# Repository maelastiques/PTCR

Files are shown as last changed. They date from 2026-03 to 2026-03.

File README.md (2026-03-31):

# PTCR -- Portable Text Communication Radio

PTCR (**Portable Text Communication Radio**) is an open hardware
LoRa-based handheld communication device designed for off‑grid
messaging.

The goal of this project is to build a **fully self‑contained radio
communicator** that can operate without cellular infrastructure,
allowing users to exchange text messages over long distances using LoRa
technology.

This project was created by **Maël**, a developer and hardware tinkerer
who enjoys:

-   hiking
-   autonomy and off‑grid systems
-   nomadic lifestyles
-   building and experimenting with electronics
-   creating whatever ideas come to mind

The idea behind PTCR came from the desire to have a **nomadic
communication tool** that works during hikes, expeditions, or remote
travel --- without relying on mobile networks.

Instead of buying a commercial device, the obvious solution was to
**build one**.

------------------------------------------------------------------------

# Device Preview

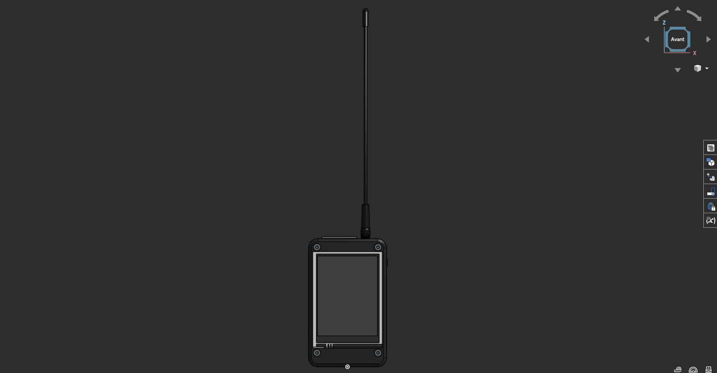
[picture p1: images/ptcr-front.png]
Device photo 1
 *Front view of the device*

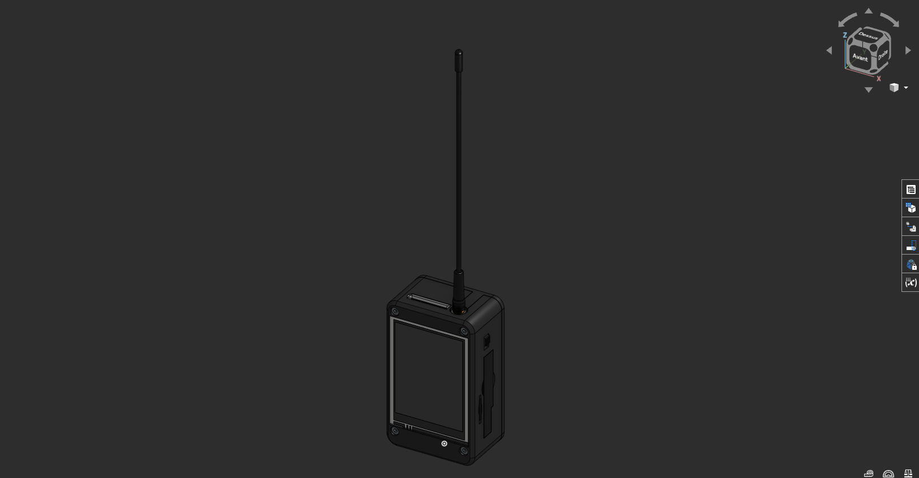
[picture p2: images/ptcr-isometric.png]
Device photo 2
 *Isometric view*

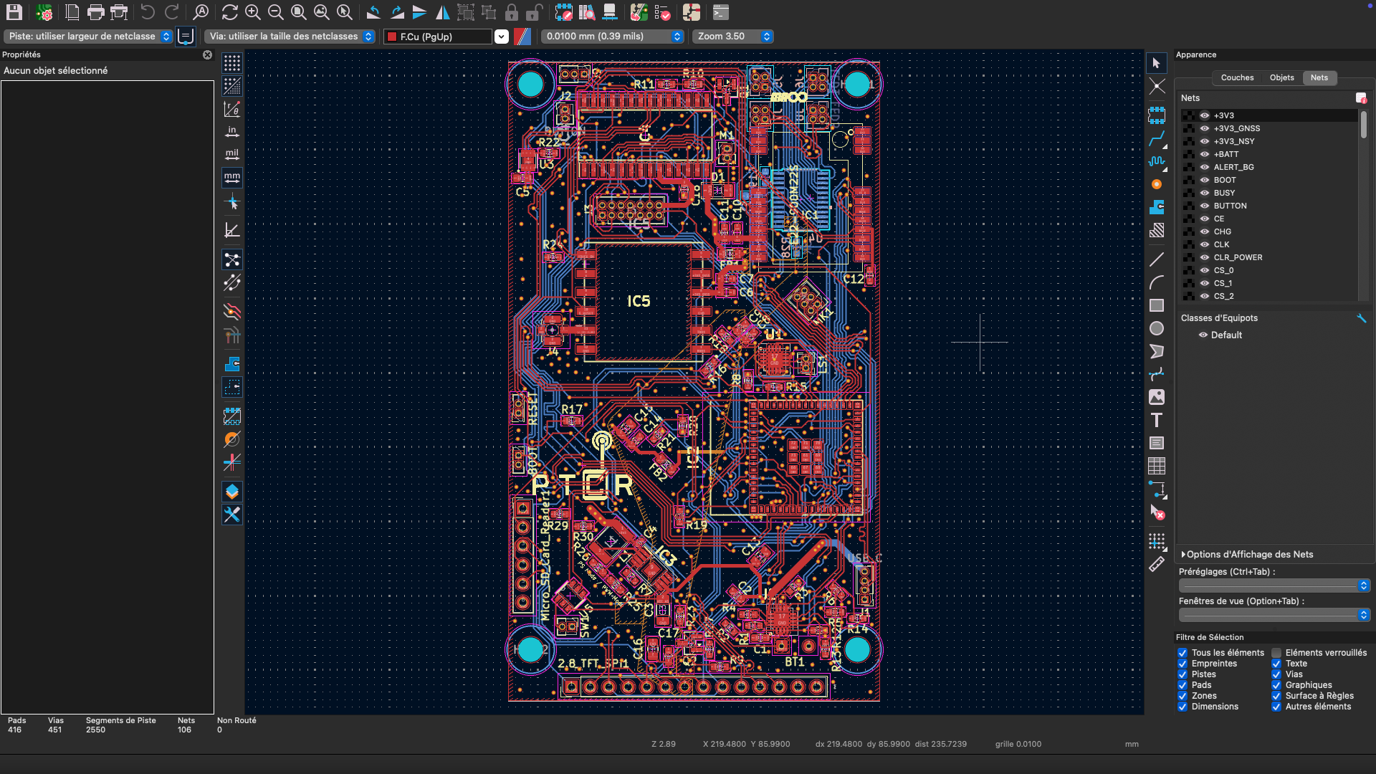
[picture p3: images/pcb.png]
Device photo 3
 *Internal electronics*

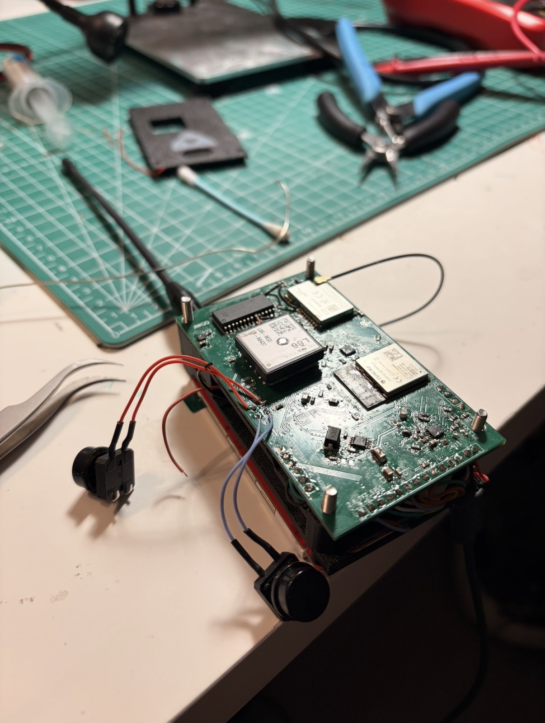
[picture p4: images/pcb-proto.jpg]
Device photo 4
 *Prototype board*

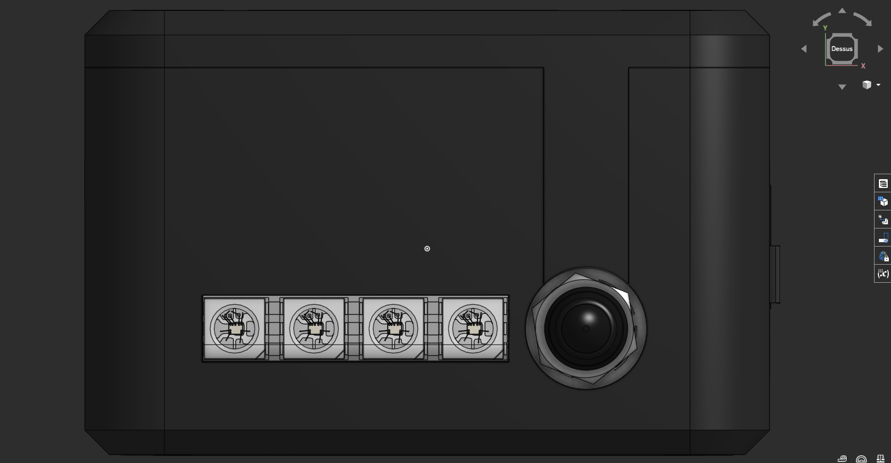
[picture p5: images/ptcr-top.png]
 *Top of the device*

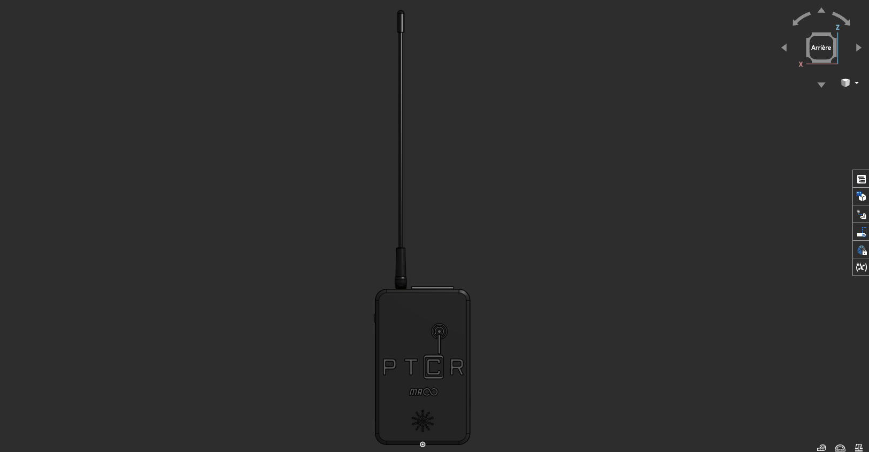
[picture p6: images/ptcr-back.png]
 *Back of the device*

------------------------------------------------------------------------

# Features

-   **LoRa long‑range communication**
-   **GNSS positioning (GPS / GLONASS)**
-   **SPI TFT display**
-   **microSD storage**
-   **LiPo battery powered**
-   **High‑efficiency 3.3V buck regulator**
-   **Open hardware**
-   Designed for **off‑grid and nomadic use**

------------------------------------------------------------------------

# Hardware Overview

The system is built around several main components:

  Component      Role
  -------------- --------------------------
  ESP32‑S3       Main MCU
  E22‑900M22S    LoRa radio module
  Quectel L86    GNSS receiver
  MCP23017       I²C GPIO expander
  TFT display    User interface
  microSD        Data storage
  TPS62842       3.3V switching regulator
  LiPo battery   Power source
  LP5012         12 PWM canals led module
  MAX16150       switch ON/OFF with push button

The PCB uses a **4‑layer stackup**:

-   Top layer: signals
-   Internal layer: **solid ground plane**
-   Internal layer: **3.3V power plane**
-   Bottom layer: signals + ground pour

This architecture improves signal integrity and RF performance.

------------------------------------------------------------------------

# Schematic

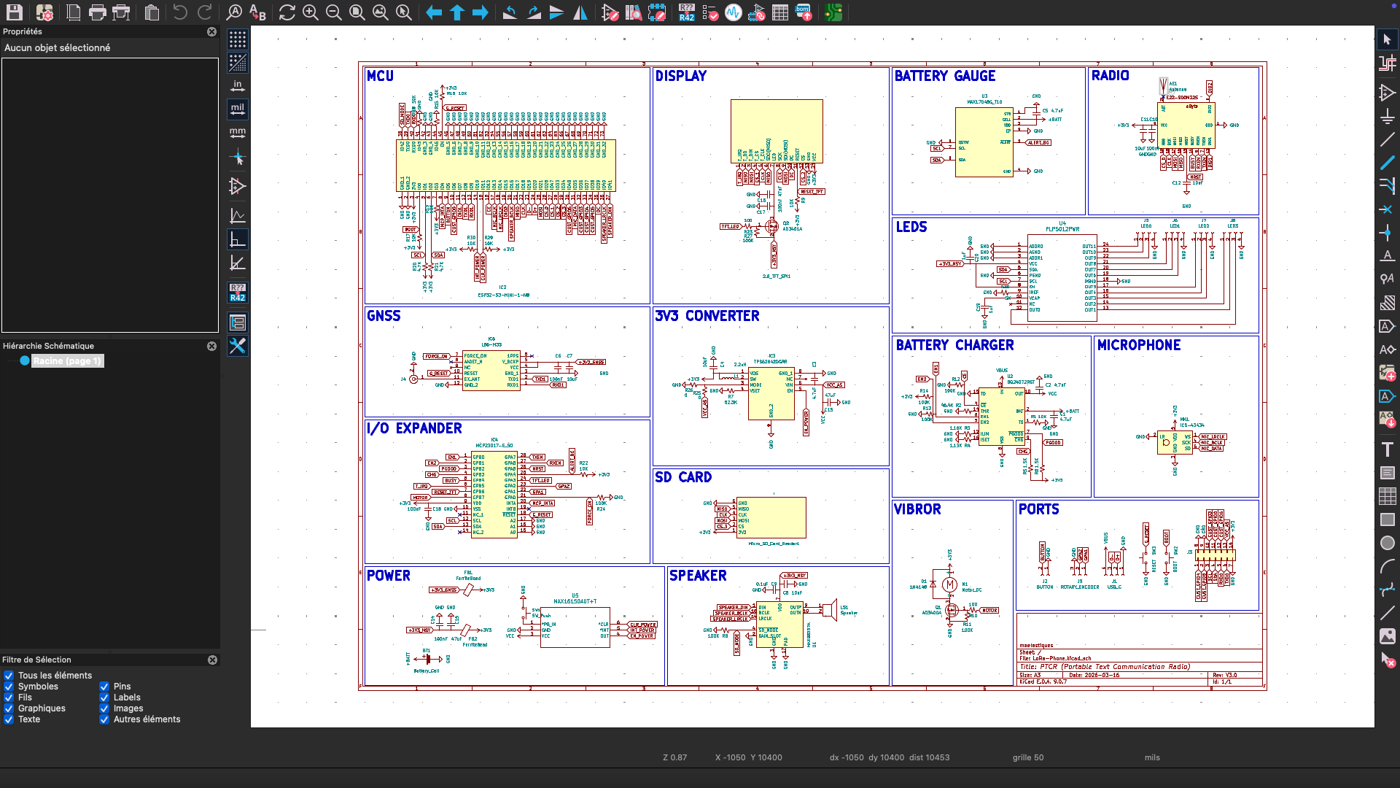
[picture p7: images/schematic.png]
PTCR schematic


------------------------------------------------------------------------

# Pin Mapping

## LoRa Module -- E22‑900M22S

  Signal   Direction    Description
  -------- ------------ ----------------------
  MISO     LoRa → MCU   SPI data from radio
  MOSI     MCU → LoRa   SPI data to radio
  SCK      MCU → LoRa   SPI clock
  NSS      MCU → LoRa   Chip select
  BUSY     LoRa → MCU   Radio busy indicator
  DIO1     LoRa → MCU   Interrupt
  RXEN     MCU → LoRa   Enable RX
  TXEN     MCU → LoRa   Enable TX
  NRST     MCU → LoRa   Reset

RXEN and TXEN are pulled down by default to guarantee a safe startup
state.

------------------------------------------------------------------------

## GNSS -- Quectel L86

  Signal   Direction       Description
  -------- --------------- ---------------
  TX       GNSS → MCU      NMEA output
  RX       MCU → GNSS      configuration
  V_BCKP   backup supply   RTC retention

------------------------------------------------------------------------

## MCP23017 -- GPIO Expander

Connected through **I²C**.

  Signal       Description
  ------------ ---------------
  SDA          I²C data
  SCL          I²C clock
  GPA0--GPA7   extended GPIO
  GPB0--GPB7   extended GPIO

Used for additional control signals and hardware expansion.

------------------------------------------------------------------------

## TFT Display (SPI)

  Signal   Description
  -------- ----------------
  MOSI     SPI data
  SCK      SPI clock
  CS       Chip select
  DC       Data / command
  RST      Reset
  BL       Backlight

------------------------------------------------------------------------

## microSD

  Signal   Description
  -------- -------------
  MOSI     SPI data
  MISO     SPI data
  SCK      SPI clock
  CS       Chip select

Shared SPI bus with other peripherals.

------------------------------------------------------------------------

## Leds module

  Connected through **I²C**.

  Signal       Description
  ------------ ---------------
  SDA          I²C data
  SCL          I²C clock
  OUT0-OUT11   12 PWM canals

Used for 4 RGB leds

------------------------------------------------------------------------

## ON/OFF module

  Signal       Description
  ------------ ---------------
  PB_IN        Button
  CLR          Input signal
  INT          Output signal

Used for turning ON and OFF the regulator

------------------------------------------------------------------------

# Power System

Power is supplied by a **single‑cell LiPo battery**.

A **TPS62842 buck converter** generates the **3.3V system rail**.

The design includes:

-   local decoupling capacitors
-   ferrite filtering
-   ground stitching vias
-   separated noisy power domains

This ensures stable operation for RF, GNSS, and digital circuits.

------------------------------------------------------------------------

# Firmware (planned)

The ESP32 firmware will provide:

-   LoRa messaging
-   device‑to‑device communication
-   contact management
-   message history on SD card
-   GNSS position logging
-   graphical interface on TFT

Future ideas:

-   mesh networking
-   encrypted messaging
-   APRS beacon support
-   offline mapping

------------------------------------------------------------------------

# Motivation

This project combines several things I enjoy:

-   hiking
-   autonomy and self‑reliance
-   radio communication
-   embedded electronics
-   building experimental devices

PTCR is meant to be a **portable communication device for nomadic use**,
especially when exploring places without network coverage.

And most importantly --- it was simply fun to build.

------------------------------------------------------------------------

# Project Status

Prototype stage !

Current revision: **PTCR V3**

Hardware and firmware are actively being developed.

------------------------------------------------------------------------

# Author

**Maël CUNY**

Software developer, robotics enthusiast, and hardware builder.

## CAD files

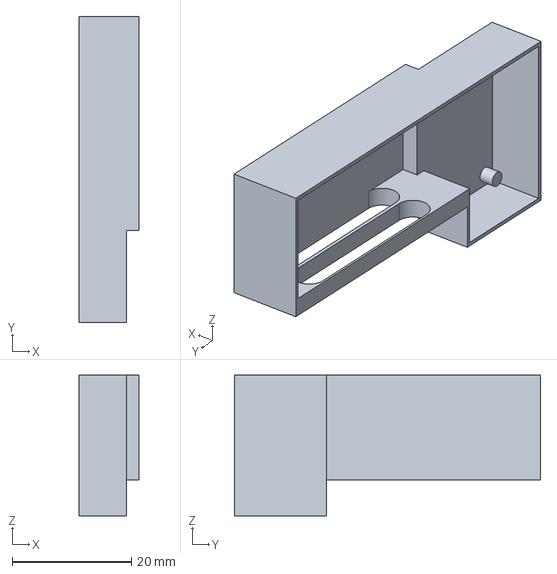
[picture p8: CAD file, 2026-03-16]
CAD/PTCR-MODULE.step
10.1 x 51.3 x 23.6 mm

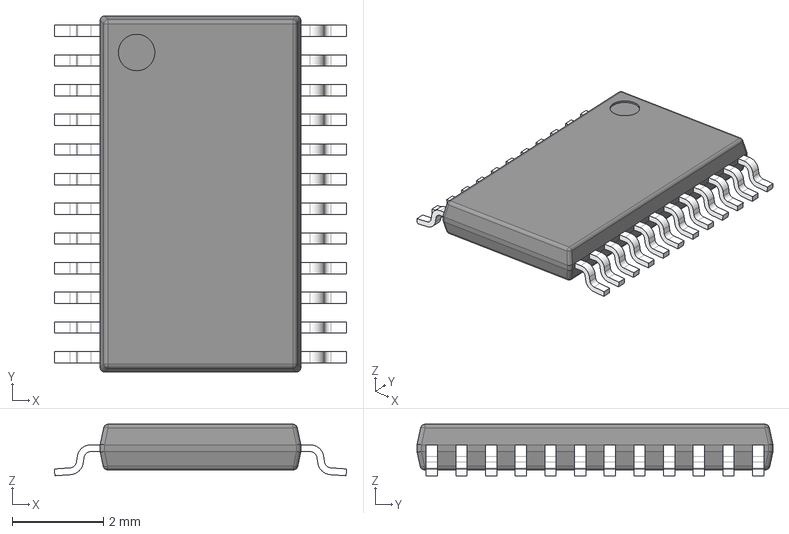
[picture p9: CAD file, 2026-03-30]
components-models/PW0024A.stp
6.40 x 7.80 x 1.13 mm
BODY-TSSOP
LEAD-TSSOP x 24
PIN1

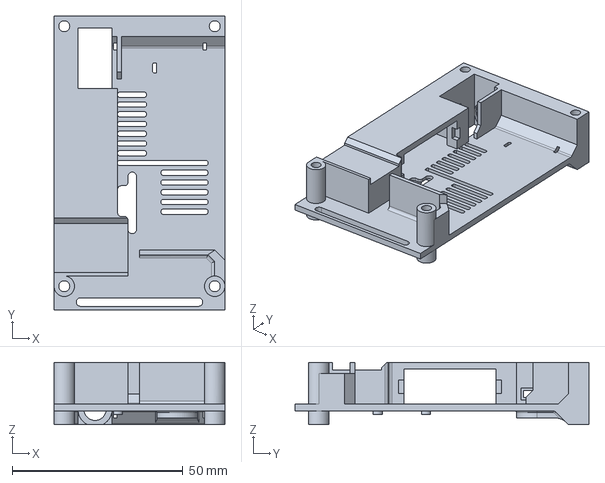
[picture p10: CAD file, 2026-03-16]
CAD/PTCR-BASE.step
50.0 x 86.0 x 18.2 mm

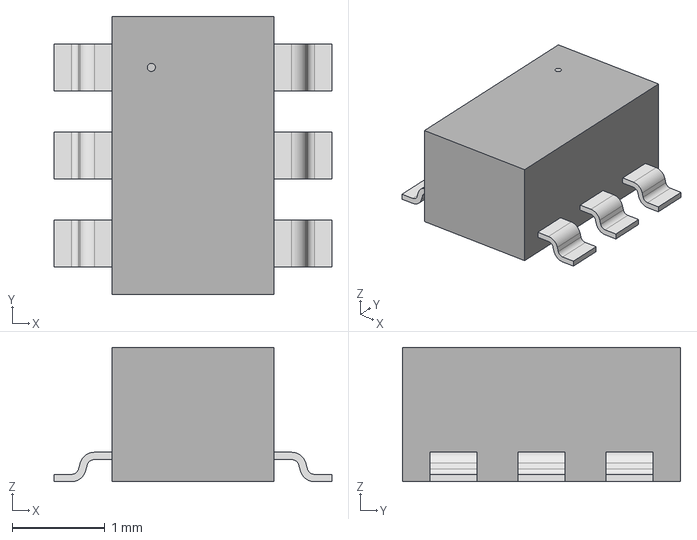
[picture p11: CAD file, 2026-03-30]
components-models/21-0058I_MXM.step
3.00 x 3.00 x 1.45 mm

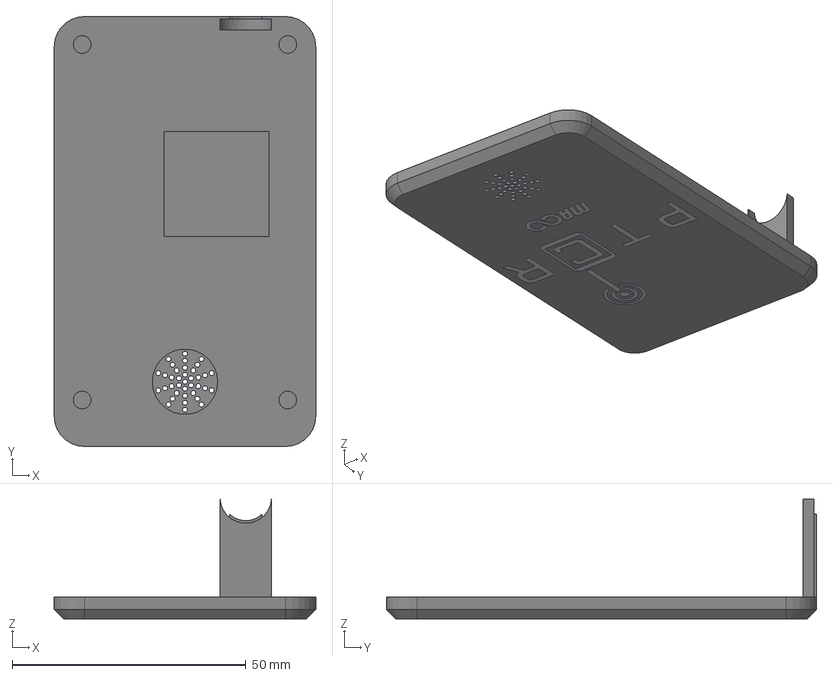
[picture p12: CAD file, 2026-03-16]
CAD/PTCR-CASING-BACK.step
56.0 x 92.0 x 25.6 mm

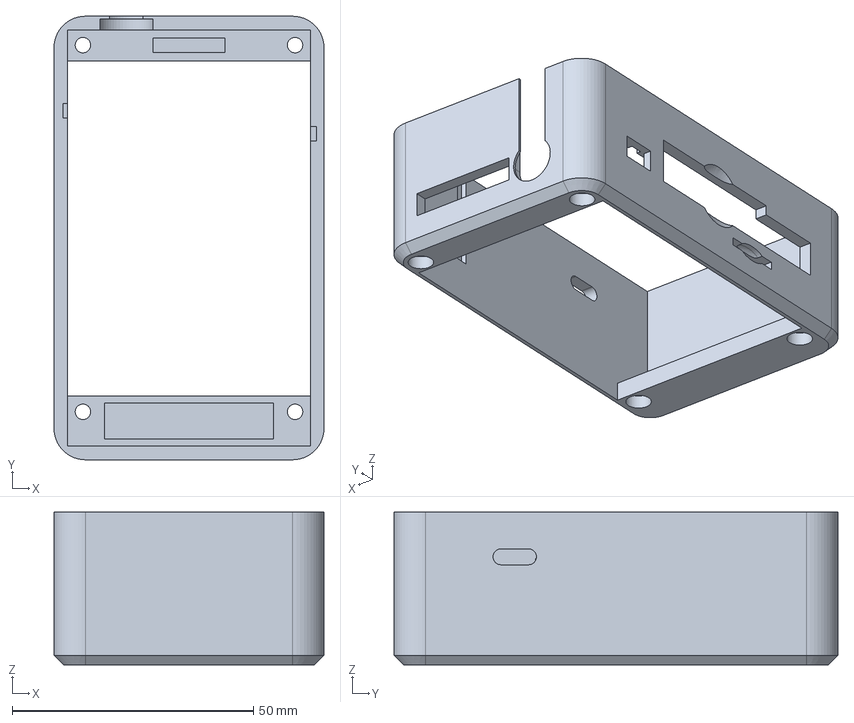
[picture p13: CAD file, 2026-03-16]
CAD/PTCR-CASING-FRONT.step
56.0 x 92.0 x 31.7 mm

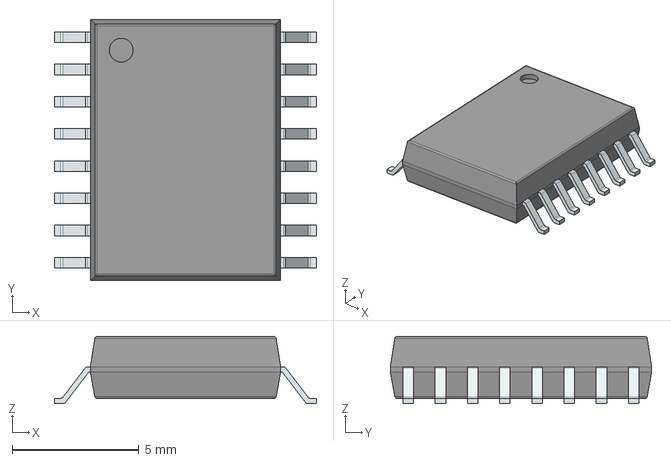
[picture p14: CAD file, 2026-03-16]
components-models/DS3231SNTR.stp
10.3 x 10.3 x 2.65 mm
PinsArrayLR

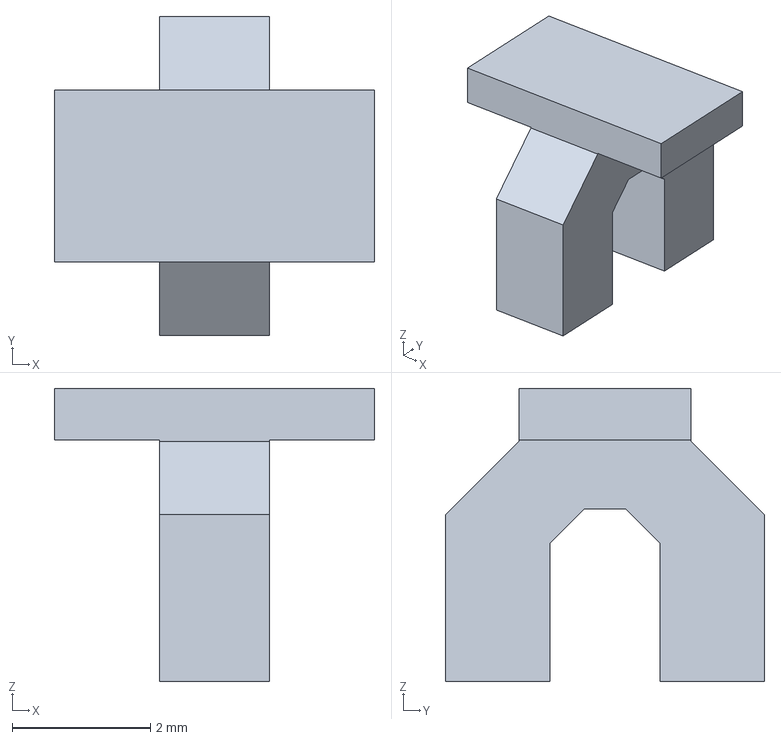
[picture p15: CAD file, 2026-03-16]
CAD/slide-switch-cover-2.step
4.64 x 4.62 x 4.25 mm

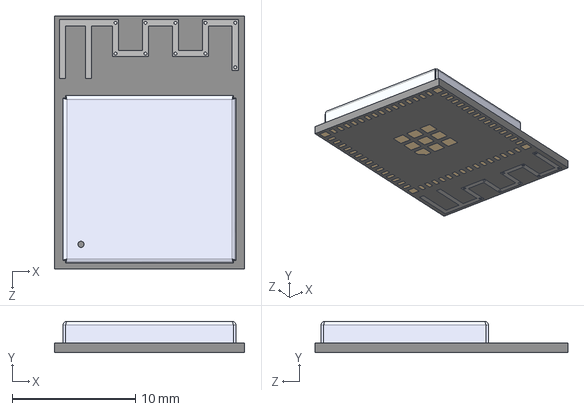
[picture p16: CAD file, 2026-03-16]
components-models/ESP32-S3-MINI-1-N8.stp
15.4 x 2.55 x 20.5 mm

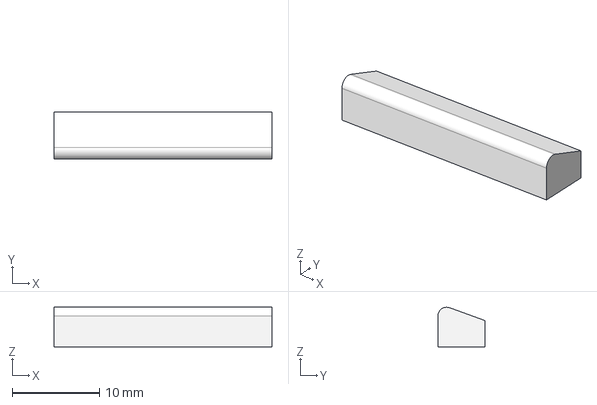
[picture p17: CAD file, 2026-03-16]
CAD/PTCR-LEDS-DIFFUSER.step
25.0 x 5.40 x 4.54 mm

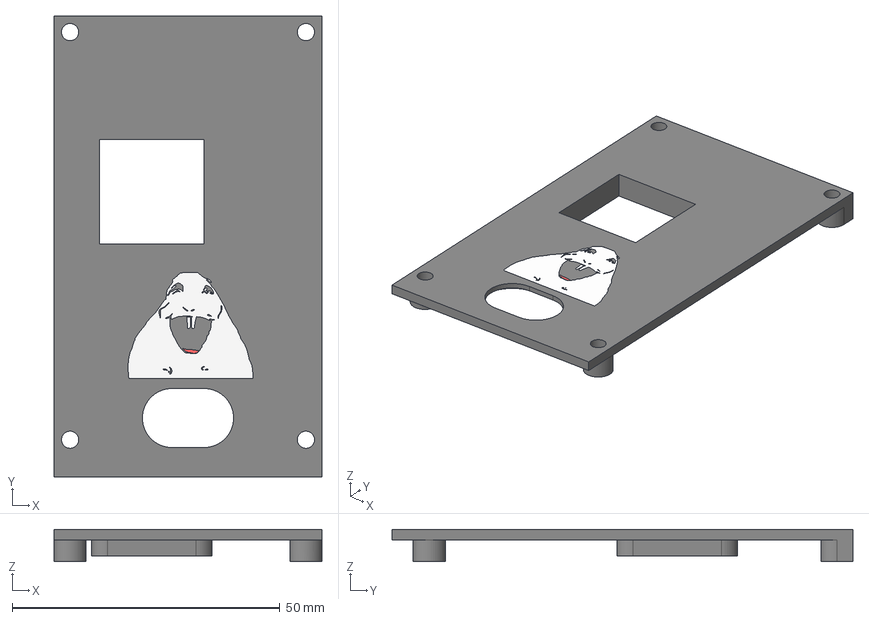
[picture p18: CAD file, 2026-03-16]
CAD/PTCR-BATTERY-HOLDER.step
50.0 x 86.0 x 6.00 mm

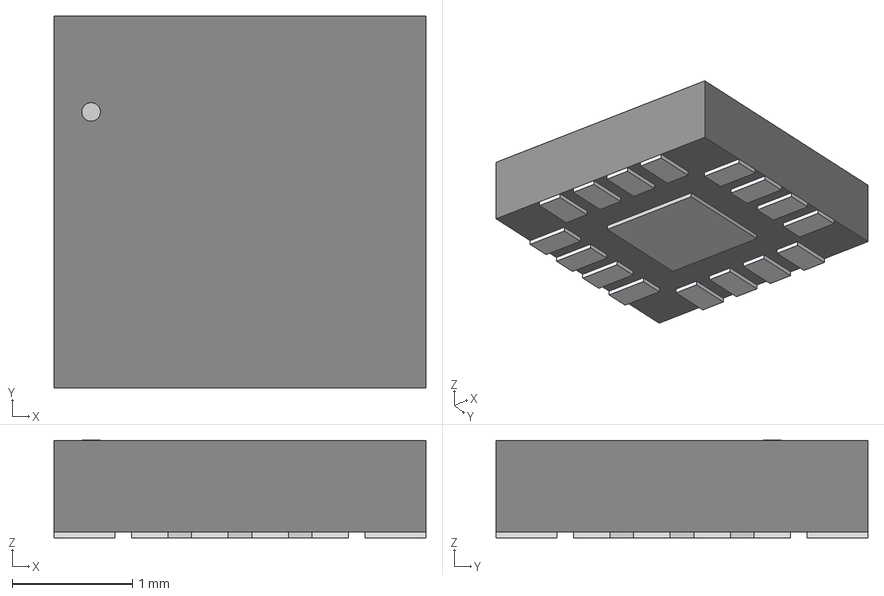
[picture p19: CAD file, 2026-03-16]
components-models/21-0136I_T1633-4_MXM.step
3.10 x 3.10 x 0.815 mm

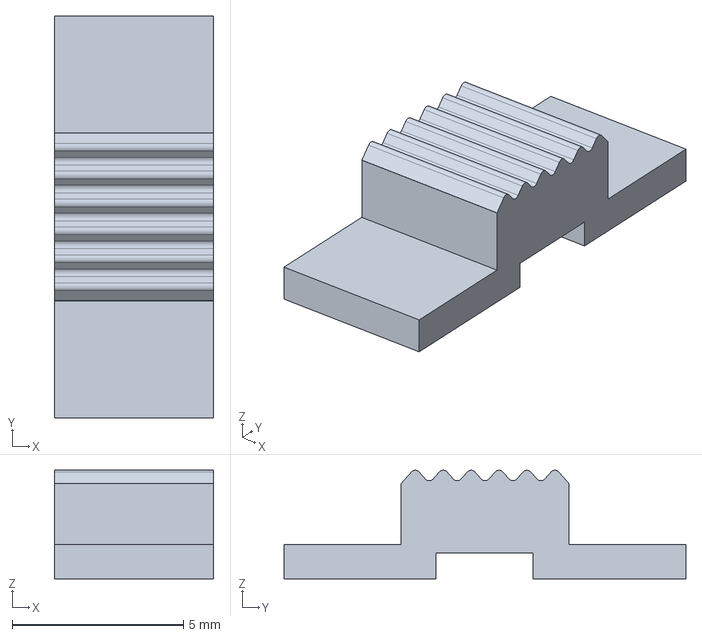
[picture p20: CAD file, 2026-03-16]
CAD/slide-switch-cover-1.step
4.65 x 11.8 x 3.17 mm

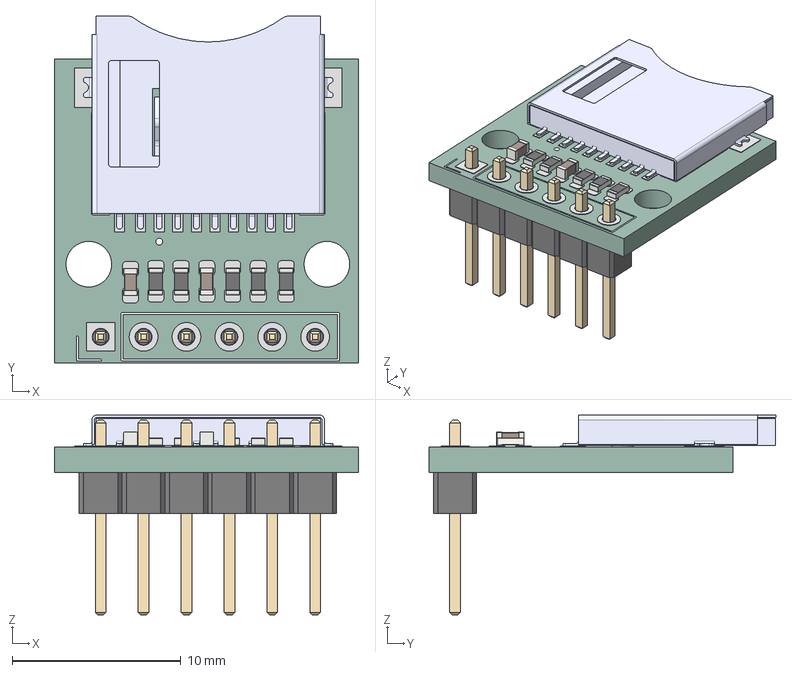
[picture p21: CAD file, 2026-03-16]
components-models/microSD_breakout_mini_pins.step
18.0 x 20.5 x 11.8 mm
R_0603_1608Metric x 5
C_0603_1608Metric x 2
MSD-11-A
PinHeader_1x06_P2.54mm_Vertical
microSD_breakout_mini_pad
microSD_breakout_mini_silkscreen x 2
microSD_breakout_mini_PCB

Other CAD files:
components-models/E22-900M22S.step
components-models/L86-M33.stp
components-models/TPS62842DGRR.stp
components-models/MCP23017-E_SO.stp
components-models/BQ24072RGTT.stp
components-models/MAX17048G_T10.step

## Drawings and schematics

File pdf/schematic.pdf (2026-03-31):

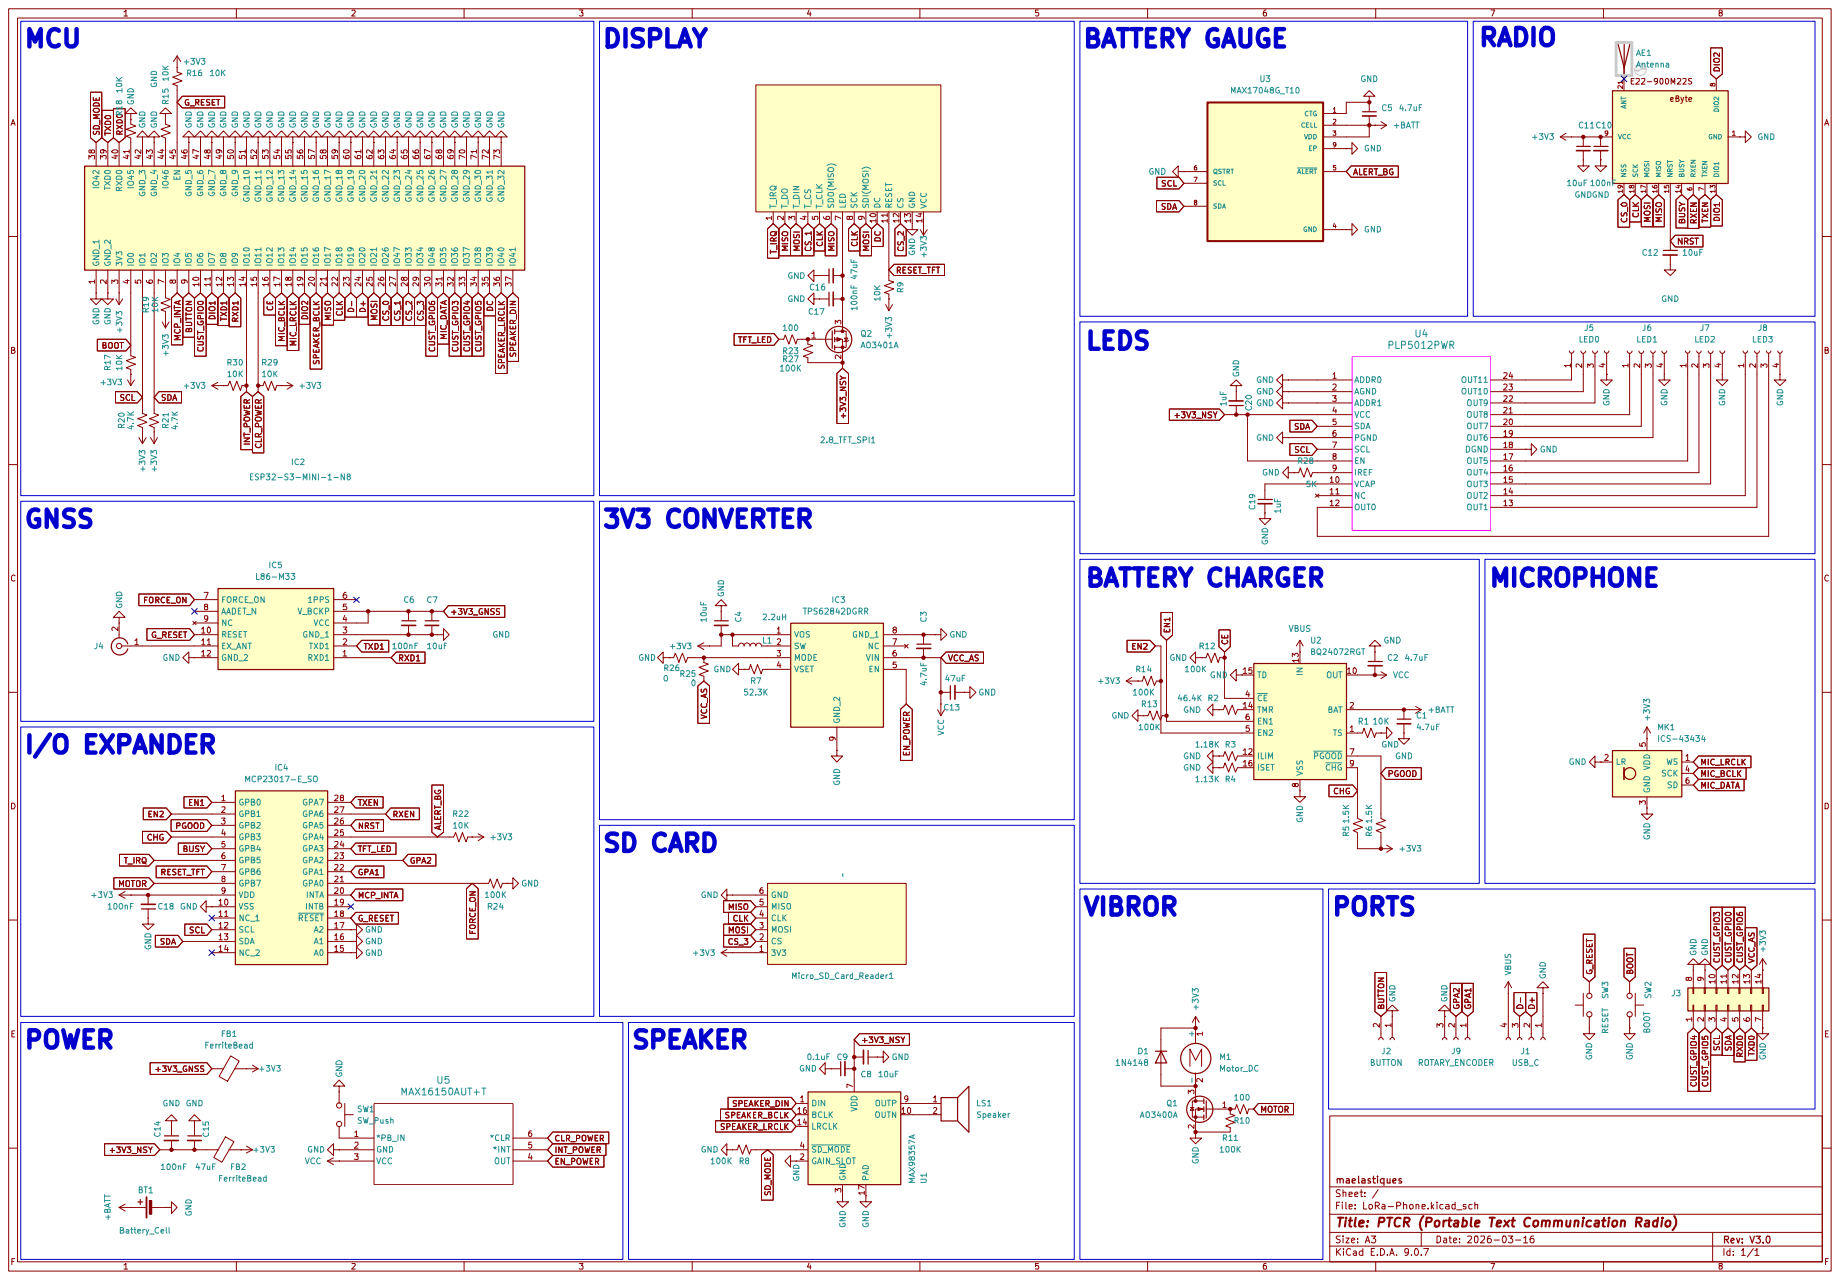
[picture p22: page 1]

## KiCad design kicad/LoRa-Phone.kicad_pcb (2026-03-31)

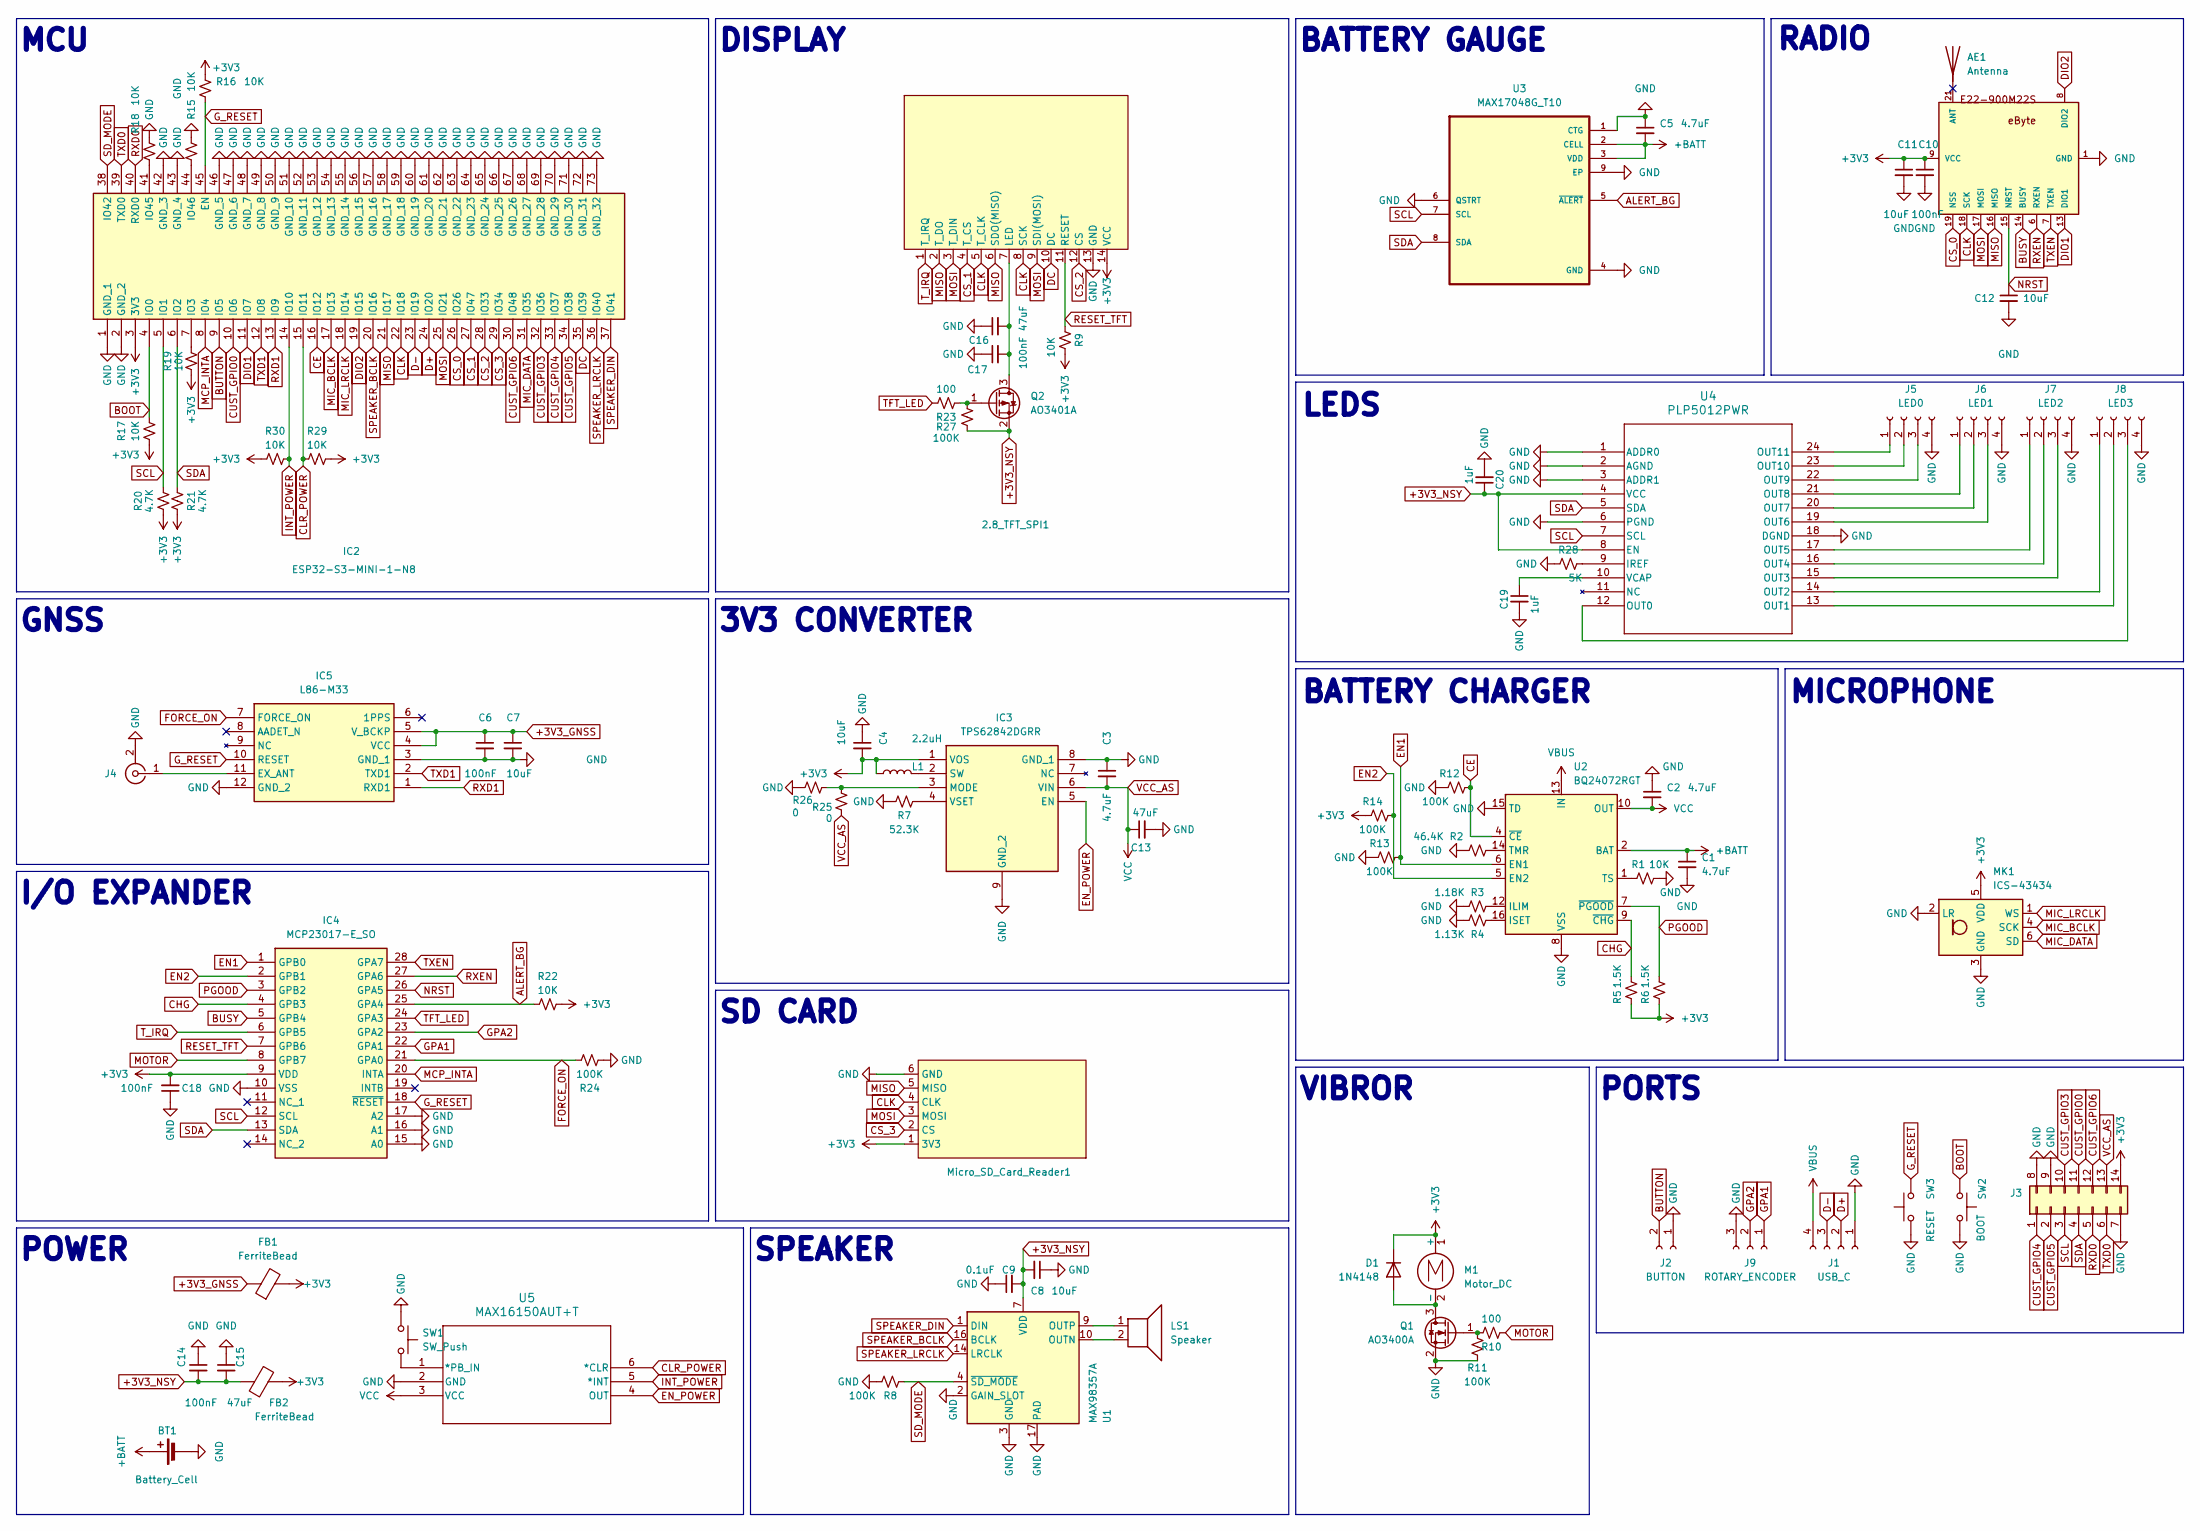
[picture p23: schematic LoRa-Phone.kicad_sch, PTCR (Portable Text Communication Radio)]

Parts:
2.8_TFT_SPI1: PinHeader_1x14_P2.54mm_Vertical
AE1: Antenna
BT1: Battery_Cell; SolderWire-0.1sqmm_1x02_P3.6mm_D0.4mm_OD1mm
C1, C2, C5: 4.7uF; C_0603_1608Metric
C3: 4.7uF; C_1206_3216Metric
C4: 10uF; C_0402_1005Metric
C6, C10, C14, C17, C18: 100nF; C_0603_1608Metric
C7, C8, C11, C12: 10uF; C_0603_1608Metric
C9: 0.1uF; C_0603_1608Metric
C13, C15, C16: 47uF; C_0805_2012Metric
C19, C20: 1uF; C_0603_1608Metric
D1: 1N4148; D_1206_3216Metric
FB1, FB2: FerriteBead; L_0805_2012Metric
IC1: E22-900M22S
IC2: ESP32-S3-MINI-1-N8; ESP32S3MINI1N8; Mouser Part Number 356-ESP32-S3-MINI1N8
IC3: TPS62842DGRR; SOP65P490X110-9N; Mouser Part Number 595-TPS62842DGRR
IC4: MCP23017-E_SO; SOIC127P1030X265-28N; Mouser Part Number 579-MCP23017-E/SO
IC5: L86-M33; L80-M39; Mouser Part Number 277-L86-M33
J1: USB_C; PinHeader_1x04_P1.27mm_Vertical
J2: BUTTON; PinHeader_1x02_P1.27mm_Vertical
J3: Conn_02x07_Top_Bottom; PinHeader_2x07_P1.27mm_Vertical
J4: Conn_Coaxial; U.FL_Molex_MCRF_73412-0110_Vertical
J5: LED0; PinHeader_2x02_P1.27mm_Vertical
J6: LED1; PinHeader_2x02_P1.27mm_Vertical
J7: LED2; PinHeader_2x02_P1.27mm_Vertical
J8: LED3; PinHeader_2x02_P1.27mm_Vertical
J9: ROTARY_ENCODER; PinHeader_1x03_P1.27mm_Vertical
L1: 2.2uH; L_1812_4532Metric
LS1: Speaker; PinHeader_1x02_P1.27mm_Vertical
M1: Motor_DC; PinHeader_1x02_P1.27mm_Vertical
MK1: ICS-43434; PinHeader_2x03_P1.27mm_Vertical
Micro_SD_Card_Reader1: PinHeader_1x06_P2.54mm_Vertical
Q1: AO3400A; SOT-23
Q2: AO3401A; SOT-23
R1, R9, R15, R16, R17, R18, R19, R22, R29, R30: 10K; R_0603_1608Metric
R2: 46.4K; R_0603_1608Metric
R3: 1.18K; R_0603_1608Metric
R4: 1.13K; R_0603_1608Metric
R5, R6: 1.5K; R_0603_1608Metric
R7: 52.3K; R_0603_1608Metric
R8, R11, R12, R13, R14, R24, R27: 100K; R_0603_1608Metric
R10, R23: 100; R_0603_1608Metric
R20, R21: 4.7K; R_0603_1608Metric
R25, R26: 0; R_0603_1608Metric_Pad0.98x0.95mm_HandSolder
R28: 5K; R_0603_1608Metric
SW1: SW_Push; PinHeader_1x02_P1.27mm_Vertical
SW2: BOOT; PinHeader_2x01_P1.27mm_Vertical
SW3: RESET; PinHeader_2x01_P1.27mm_Vertical
U1: MAX98357A; QFN50P300X300X100-17N-D
U2: BQ24072RGT; QFN50P300X300X100-17N-D
U3: MAX17048G_T10; SON50P200X200X80-9N
U4: PLP5012PWR; TSSOP24_PW_TEX
U5: MAX16150AUT+T; 21-0058I_MXM

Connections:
+3V3: 2.8_TFT_SPI1.14 (VCC), C4.2, C10.1, C11.1, C18.2, D1.1 (K), FB1.2, FB2.1, IC1.9 (VCC), IC2.3 (3V3), IC3.1 (VOS), IC4.9 (VDD), J3.14, L1.1, M1.1 (+), MK1.5 (VDD), Micro_SD_Card_Reader1.1 (3V3), R5.1, R6.1, R9.1, R14.1, R16.2, R17.1, R19.2, R20.1, R21.1, R22.2, R29.1, R30.1
+3V3_GNSS: C6.1, C7.1, FB1.1, IC5.4 (VCC), IC5.5 (V_BCKP)
+3V3_NSY: C8.2, C9.2, C14.2, C15.2, C20.1, FB2.2, Q2.2 (S), R27.2, U1.7 (VDD), U1.8 (VDD), U4.4 (VCC), U4.8 (EN)
+BATT: BT1.1 (+), C1.1, C5.2, U2.2 (BAT), U2.3 (BAT), U3.2 (CELL), U3.3 (VDD)
ALERT_BG: IC4.25 (GPA4), R22.1, U3.5 (~ALERT)
BOOT: IC2.4 (IO0), R17.2, SW2.1
BUSY: IC1.14 (BUSY), IC4.5 (GPB4)
BUTTON: IC2.9 (IO5), J2.2
CE: IC2.16 (IO12), R12.2, U2.4 (~CE)
CHG: IC4.4 (GPB3), R5.2, U2.9 (~CHG)
CLK: 2.8_TFT_SPI1.5 (T_CLK), 2.8_TFT_SPI1.8 (SCK), IC1.18 (SCK), IC2.22 (IO18), Micro_SD_Card_Reader1.4 (CLK)
CLR_POWER: IC2.15 (IO11), R29.2, U5.6 (*CLR)
CS_0: IC1.19 (NSS), IC2.26 (IO26)
CS_1: 2.8_TFT_SPI1.4 (T_CS), IC2.27 (IO47)
CS_2: 2.8_TFT_SPI1.12 (CS), IC2.28 (IO33)
CS_3: IC2.29 (IO34), Micro_SD_Card_Reader1.2 (CS)
CUST_GPIO0: IC2.10 (IO6), J3.11
CUST_GPIO3: IC2.32 (IO36), J3.10
CUST_GPIO4: IC2.33 (IO37), J3.1
CUST_GPIO5: IC2.34 (IO38), J3.2
CUST_GPIO6: IC2.30 (IO48), J3.12
D+: IC2.24 (IO20), J1.2
D-: IC2.23 (IO19), J1.3
DC: 2.8_TFT_SPI1.10 (DC), IC2.35 (IO39)
DIO1: IC1.13 (DIO1), IC2.11 (IO7)
DIO2: IC1.8 (DIO2), IC2.19 (IO15)
EN1: IC4.1 (GPB0), R13.2, U2.6 (EN1)
EN2: IC4.2 (GPB1), R14.2, U2.5 (EN2)
EN_POWER: IC3.5 (EN), U5.4 (OUT)
FORCE_ON: IC4.21 (GPA0), IC5.7 (FORCE_ON), R24.1
GND: 2.8_TFT_SPI1.13 (GND), BT1.2 (-), C1.2, C2.1, C3.1, C4.1, C5.1, C6.2, C7.2, C8.1, C9.1, C10.2, C11.2, C12.2, C13.2, C14.1, C15.1, C16.1, C17.1, C18.1, C19.2, C20.2, IC1.1 (GND), IC1.2 (GND), IC1.3 (GND), IC1.4 (GND), IC1.5 (GND), IC1.10 (GND), IC1.11 (GND), IC1.12 (GND), IC1.20 (GND), IC1.22 (GND), IC2.1 (GND_1), IC2.2 (GND_2), IC2.42 (GND_3), IC2.43 (GND_4), IC2.46 (GND_5), IC2.47 (GND_6), IC2.48 (GND_7), IC2.49 (GND_8), IC2.50 (GND_9), IC2.51 (GND_10), IC2.52 (GND_11), IC2.53 (GND_12), IC2.54 (GND_13), IC2.55 (GND_14), IC2.56 (GND_15), IC2.57 (GND_16), IC2.58 (GND_17), IC2.59 (GND_18), IC2.60 (GND_19), IC2.61 (GND_20), IC2.62 (GND_21), IC2.63 (GND_22), IC2.64 (GND_23), IC2.65 (GND_24), IC2.66 (GND_25), IC2.67 (GND_26), IC2.68 (GND_27), IC2.69 (GND_28), IC2.70 (GND_29), IC2.71 (GND_30), IC2.72 (GND_31), IC2.73 (GND_32), IC3.8 (GND_1), IC3.9 (GND_2), IC4.10 (VSS), IC4.15 (A0), IC4.16 (A1), IC4.17 (A2), IC5.3 (GND_1), IC5.12 (GND_2), J1.1, J2.1, J3.7, J3.8, J3.9, J4.2 (Ext), J5.4, J6.4, J7.4, J8.4, J9.3, MK1.2 (LR), MK1.3 (GND), Micro_SD_Card_Reader1.6 (GND), Q1.2 (S), R1.2, R2.1, R3.1, R4.1, R7.1, R8.2, R11.2, R12.1, R13.1, R15.2, R18.2, R24.2, R26.1, R28.2, SW1.1, SW2.2, SW3.1, U1.2 (GAIN_SLOT), U1.3 (GND), U1.11 (GND), U1.15 (GND), U1.17 (PAD), U2.8 (VSS), U2.15 (TD), U2.17 (VSS), U3.1 (CTG), U3.4 (GND), U3.6 (QSTRT), U3.9 (EP), U4.1 (ADDR0), U4.2 (AGND), U4.3 (ADDR1), U4.6 (PGND), U4.18 (DGND), U5.2 (GND)
GPA1: IC4.22 (GPA1), J9.1
GPA2: IC4.23 (GPA2), J9.2
G_RESET: IC2.45 (EN), IC4.18 (~RESET), IC5.10 (RESET), R16.1, SW3.2
INT_POWER: IC2.14 (IO10), R30.2, U5.5 (*INT)
MCP_INTA: IC2.8 (IO4), IC4.20 (INTA)
MIC_BCLK: IC2.17 (IO13), MK1.4 (SCK)
MIC_DATA: IC2.31 (IO35), MK1.6 (SD)
MIC_LRCLK: IC2.18 (IO14), MK1.1 (WS)
MISO: 2.8_TFT_SPI1.2 (T_DO), 2.8_TFT_SPI1.6 (SDO(MISO)), IC1.16 (MISO), IC2.21 (IO17), Micro_SD_Card_Reader1.5 (MISO)
MOSI: 2.8_TFT_SPI1.3 (T_DIN), 2.8_TFT_SPI1.9 (SDI(MOSI)), IC1.17 (MOSI), IC2.25 (IO21), Micro_SD_Card_Reader1.3 (MOSI)
MOTOR: IC4.8 (GPB7), R10.2
NRST: C12.1, IC1.15 (NRST), IC4.26 (GPA5)
unnamed: 2.8_TFT_SPI1.7 (LED), C16.2, C17.2, Q2.3 (D)
unnamed: AE1.1, IC1.21 (ANT)
unnamed: D1.2 (A), M1.2 (-), Q1.3 (D)
unnamed: IC2.7 (IO3), R19.1
unnamed: IC2.41 (IO45), R18.1
unnamed: IC2.44 (IO46), R15.1
unnamed: IC3.3 (MODE), R25.2, R26.2
unnamed: IC3.2 (SW), L1.2
unnamed: IC3.4 (VSET), R7.2
unnamed: IC5.11 (EX_ANT), J4.1 (In)
unnamed: J5.1, U4.24 (OUT11)
unnamed: J5.2, U4.23 (OUT10)
unnamed: J5.3, U4.22 (OUT9)
unnamed: J6.1, U4.21 (OUT8)
unnamed: J6.2, U4.20 (OUT7)
unnamed: J6.3, U4.19 (OUT6)
unnamed: J7.1, U4.17 (OUT5)
unnamed: J7.2, U4.16 (OUT4)
unnamed: J7.3, U4.15 (OUT3)
unnamed: J8.1, U4.14 (OUT2)
unnamed: J8.2, U4.13 (OUT1)
unnamed: J8.3, U4.12 (OUT0)
unnamed: Q1.1 (G), R10.1, R11.1
unnamed: Q2.1 (G), R23.2, R27.1
unnamed: LS1.2, U1.10 (OUTN)
unnamed: LS1.1, U1.9 (OUTP)
unnamed: R3.2, U2.12 (ILIM)
unnamed: R4.2, U2.16 (ISET)
unnamed: R2.2, U2.14 (TMR)
unnamed: R1.1, U2.1 (TS)
unnamed: R28.1, U4.9 (IREF)
unnamed: C19.1, U4.10 (VCAP)
unnamed: SW1.2, U5.1 (*PB_IN)
PGOOD: IC4.3 (GPB2), R6.2, U2.7 (~PGOOD)
RESET_TFT: 2.8_TFT_SPI1.11 (RESET), IC4.7 (GPB6), R9.2
RXD0: IC2.40 (RXD0), J3.5
RXD1: IC2.13 (IO9), IC5.1 (RXD1)
RXEN: IC1.6 (RXEN), IC4.27 (GPA6)
SCL: IC2.5 (IO1), IC4.12 (SCL), J3.3, R20.2, U3.7 (SCL), U4.7 (SCL)
SDA: IC2.6 (IO2), IC4.13 (SDA), J3.4, R21.2, U3.8 (SDA), U4.5 (SDA)
SD_MODE: IC2.38 (IO42), R8.1, U1.4 (~SD_MODE)
SPEAKER_BCLK: IC2.20 (IO16), U1.16 (BCLK)
SPEAKER_DIN: IC2.37 (IO41), U1.1 (DIN)
SPEAKER_LRCLK: IC2.36 (IO40), U1.14 (LRCLK)
TFT_LED: IC4.24 (GPA3), R23.1
TXD0: IC2.39 (TXD0), J3.6
TXD1: IC2.12 (IO8), IC5.2 (TXD1)
TXEN: IC1.7 (TXEN), IC4.28 (GPA7)
T_IRQ: 2.8_TFT_SPI1.1 (T_IRQ), IC4.6 (GPB5)
VBUS: J1.4, U2.13 (IN)
VCC_AS: C2.2, C3.2, C13.1, IC3.6 (VIN), J3.13, R25.1, U2.10 (OUT), U2.11 (OUT), U5.3 (VCC)

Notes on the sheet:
LEDS
VIBROR
I/O EXPANDER
DISPLAY
PORTS
RADIO
POWER
MICROPHONE
GNSS
BATTERY GAUGE
BATTERY CHARGER
SPEAKER
SD CARD
3V3 CONVERTER
MCU

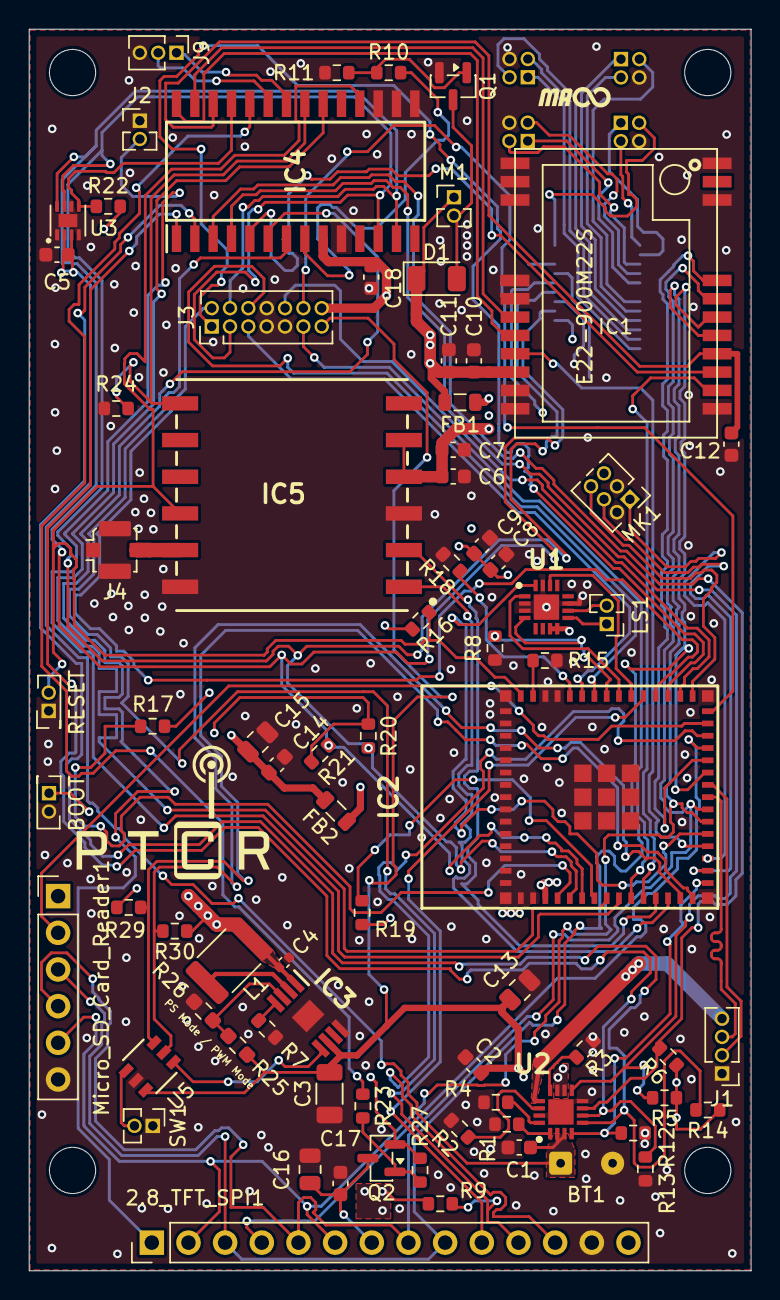
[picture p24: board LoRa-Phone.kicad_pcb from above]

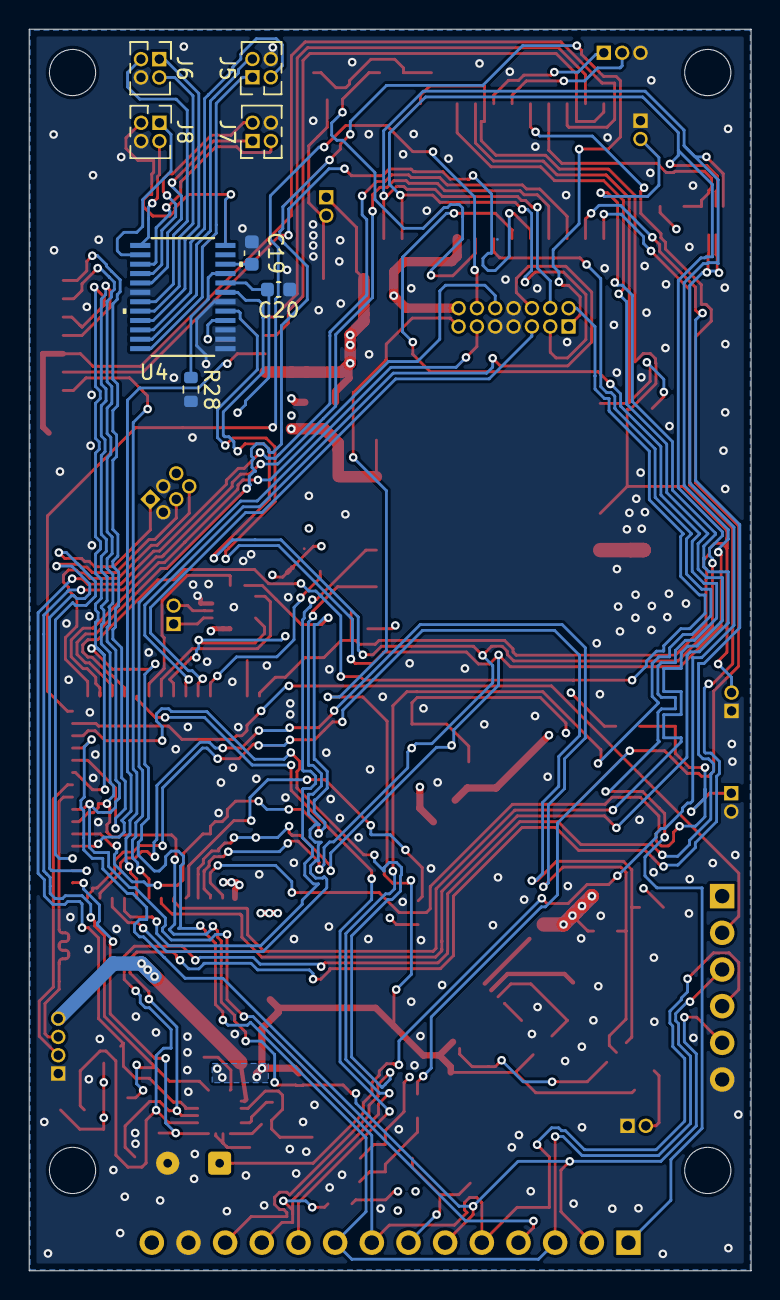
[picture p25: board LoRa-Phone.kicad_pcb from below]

Board: 4 copper layers, 50.0 x 86.0 mm, 88 parts (8 on the bottom side), 93 nets.

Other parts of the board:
HOLE0, HOLE1, HOLE2, HOLE3: MountingHole_3.2mm_M3

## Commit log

2026-03-16 First commit, added KiCad project and components's 3D models
    [21-0136I_T1633-4_MXM.step, BQ24072RGTT.stp, DS3231SN#T&R.stp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]
2026-03-16 Added CAD and README
    [21-0136I_T1633-4_MXM.step, BQ24072RGTT.stp, DS3231SN#T&R.stp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]
2026-03-16 Modified README
    [LoRa-Phone.kicad_pcb, LoRa-Phone.kicad_sch]
2026-03-30 added component models
    [21-0058I_MXM.step, DS3231SNTR.stp, PW0024A.stp]
2026-03-31 release:100 Third version
    [LoRa-Phone.kicad_pcb, LoRa-Phone.kicad_sch]
